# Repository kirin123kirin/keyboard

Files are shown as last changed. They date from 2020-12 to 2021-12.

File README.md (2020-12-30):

# 自作キーボードの沼

## 以下の要件を満たす分割キーボードがないから作りたい。

* 癖のない一般的なキーピッチ、配列である
* 日本語配列である
* 光らなくてよい
* 一般的なテンキーレスを普通に左右に分割しただけで特殊な配列ではないこと
* 「6」、「Y」、「B」は右手で押す
* IME切り替えはトグルではなくMacのように「英数」、「かな」で独立したキー切替をする
* USB Type-C
* 左右どちら側のUSBに接続しても使える
* キーキャップにかな表記はいらない
* キーキャップに英語配列時の記号も小さく表記したい
* Thinkpad トラックポイントを右手側につけたい

## 沼１：レイアウト
1. [レイアウトを考える](http://www.keyboard-layout-editor.com/)

## 沼２：回路基盤設計
2. [回路図の書き方](https://www.youtube.com/watch?v=dNfaLM5PUVM&list=PLKe0_8RR2yrSu2fZAs2D8_bfYQ3JGBO-w)
3. [自動レイアウト](https://github.com/yskoht/keyboard-layouter)
4. [自動配線](https://freerouting.mihosoft.eu/)
5. [Elecrow発注データ作成は自作](https://github.com/kirin123kirin/keyboard/blob/main/pcb/basic_L/garbar.py)

## 沼３：ファームウェア書き込み
6. [半自動firmware作成](https://kbfirmware.com/)
   -> Or import from keyboard-layout-editor.comの下のテキストボックスにKyeboard Layout Editorのraw dataの内容をコピペ

## 沼４：スイッチ選び
7. 赤軸(軽い) or 黒軸(重い) / CherryMX(90円) or KailhBox(40円)

## 沼５：キーキャップ選び
8. [Filco交換用](https://amzn.to/37BaPCG)

9. [刻印サービス](https://yushakobo.jp/keycap-laser-marking/)
  -> 高いのでやめる

## 沼６：ケース作成
10. [Plate & Case Builder](http://builder.swillkb.com/)
  -> keyboard-layout-editorのRAWデータからCADデータ自動作成

11. [Kicad PCB to Fusion360](https://garchiving.com/output-3d-model-with-kicad/)

12. [Elecrow 3D Printing Service](https://www.elecrow.com/3d-printing-service.html)

## 沼７：トラックポイントをつける
TODO

## かかった費用

| カテゴリー 	| 購入製品 	| 個数  	| 単価 	| 小計(円)  	| 購入店 	|
| :--- | :---  | ---:  | ---: | ---: | :---  |
| マイコンボード 	| [Elite-C](https://yushakobo.jp/shop/elite-c/) 	| 2 	| 2805 	| 5610 	| [遊舎工房](https://yushakobo.jp/shop/elite-c/) 	|
| マイコンボードソケット化 	| [ピンヘッダー ストリップ ピンソケット 40ピン](https://amzn.to/2Ml5kjq) 	| 1 	| 720 	| 720 	| [Amazon](https://amzn.to/2Ml5kjq) 	|
| PCB基盤 	| 左 	| 104.1 	| $27.35  	| 2,847 	| ElecrowPCB 	|
| PCB基盤 	| 右 	| 104.1 	| $36.37  	| 3,786 	| ElecrowPCB 	|
| PCB基盤 	| 送料 	| 104.1 	| $20.12  	| 2,094 	| ElecrowPCB 	|
| ケース 	| 左右光造形 	| 104.1 	| $70 	| 7,287 	| Elecrow3DPrintService 	|
| ケース 	| トッププレート 	| 104.1 	| $20 	| 2,082 	| Elecrow3DPrintService 	|
| ケース 	| 送料 	| 104.1 	| $14 	| 1,447  	| Elecrow3DPrintService 	|
| キースイッチ 	| [Kailh Box黒軸](https://amzn.to/3h1IFUD) 	| 104.1 	| $34 	| 3508.17  	| Aliexpress 	|
| スタビライザー 	| [ブラックチェリースタビライザー](https://ja.aliexpress.com/item/32831318362.html?spm=a2g0s.9042311.0.0.46c54c4d9BF958) 	| 104.1 	| $5.90 	| 614.19 	| Aliexpress 	|
| キーキャップ 	| [Majestouch 交換用キーキャップセット 日本語108キー・かななし](https://amzn.to/37BaPCG) 	| 1 	| 3420 	| 3420 	| [Amazon](https://amzn.to/37BaPCG)	|
| 配線類 	| [ダイオード500個](https://amzn.to/2Wz1wNc) 	| 1 	| 1082 	| 1082 	| [Amazon](https://amzn.to/2Wz1wNc) 	|
| 配線類 	| [抵抗セット](https://amzn.to/3nESg6m) 	| 1 	| 890 	| 890 	| [Amazon](https://amzn.to/3nESg6m) 	|
| 配線類 	| [はんだ線](https://amzn.to/3mBjyJs)、[フラックス](https://amzn.to/3p1iNLk) 	| 1 	| 916 	| 916 	| [Amazon](https://amzn.to/3p1iNLk) 	|
| TRRS 	| [３．５ｍｍ４極ミニジャック　基板取付用　ＭＪ－４ＰＰ－９](https://akizukidenshi.com/catalog/g/gC-06070/) 	| 2 	| 55 	| 110 	| 秋月通商 	|
| デバック用 	| [ブレッドボード5個セット](https://amzn.to/3nD7uZn) 	| 1 	| 750 	| 750 	| [Amazon](https://amzn.to/3nD7uZn) 	|
| デバック用 	| [マスキングテープ3個](https://amzn.to/2J5NEa9) 	| 1 	| 498 	| 498 	| [Amazon](https://amzn.to/2J5NEa9) 	|
| デバック用 	| ジャンパー線、[タクトスイッチ10個](https://amzn.to/3mDJrrU) 	| 1 	| 660 	| 660 	| 秋月通商,[Amazon](https://amzn.to/3mDJrrU) 	|
| 工具 	| [はんだキット](https://amzn.to/2WwUdWA) 	| 1 	| 3599 	| 3599 	| [Amazon](https://amzn.to/2WwUdWA) 	|
| 工具 	| [ノギス](https://amzn.to/3mIHx9L) 	| 1 	| 799 	| 799 	| [Amazon](https://amzn.to/3mIHx9L)	|
| レイアウト設計 	| [キーボードレイアウト設計](http://www.keyboard-layout-editor.com/) 	| 1 	| 0 	| 0 	| OSS 	|
| PCB設計 	| [Kicad](https://kicad.org/) 	| 1 	| 0 	| 0 	| OSS 	|
| PCB設計 	| [基盤自動レイアウトプラグイン](https://github.com/yskoht/keyboard-layouter) 	| 1 	| 0 	| 0 	| OSS 	|
| PCB設計 	| [freerouting(基盤自動配線)](https://github.com/freerouting/freerouting) 	| 1 	| 0 	| 0 	| OSS 	|
| ケース、トッププレート設計 	| [Fusion360個人利用](https://www.autodesk.co.jp/products/fusion-360/overview) 	| 1 	| 0 	| 0 	| Adobe 	|
| Firmware 	| [qmk_firmware](https://github.com/qmk/qmk_firmware) 	| 1 	| 0 	| 0 	| Github 	|
| Firmware 	| [Keyboard Firmware Builder](https://kbfirmware.com/) 	| 1 	| 0 	| 0 	| OSS 	|
| Firmwareビルド用 	| [Ubuntu18.04LTS Server](http://ftp.riken.jp/Linux/ubuntu-releases/18.04/) 	| 1 	| 0 	| 0 	| Ubuntu 	|
| Firmwareソース編集用	| [Visual Studio2019Comunity](https://visualstudio.microsoft.com/ja/downloads/) 	| 1 	| 0 	| 0 	| MicroSoft 	|
| 	| 	| 	| 合計 	| 42,334円	|

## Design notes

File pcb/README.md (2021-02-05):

** qmk data version rev1 later **

# 自作基盤設計データ
## Lisense
This software is released under the [Creative Commons CC-BY-SA 4.0 License](https://creativecommons.org/licenses/by-sa/4.0/legalcode), see LICENSE.

## [Powerd by Kicad](https://kicad.org/)

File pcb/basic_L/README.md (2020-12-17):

Powered by [Keyboard Layouter](https://github.com/yskoht/keyboard-layouter) plugin.

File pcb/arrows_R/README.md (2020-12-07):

# Keyboard Layouter Playground

A sample circuit and netlist to quickly try the [Keyboard Layouter](https://github.com/yskoht/keyboard-layouter) plugin.

The sample JSON files are follow:

- ANSI 104
- ISO 105
- ErgoDox
- Atreus

## Curcuit

curcuit

## Footprint

footprint

## Lisense

This software is released under the [Creative Commons CC-BY-SA 4.0 License](https://creativecommons.org/licenses/by-sa/4.0/legalcode), see LICENSE.

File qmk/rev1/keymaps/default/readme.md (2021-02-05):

# Left Elite-C PIN asign

```
      Wheel Mouse KEY   PIN_L                               PIN_R KEY   Mouse Wheel 
                                                            Vbus                    
                        D3    TX                      RAW   B0                      
                  SIG   D2    RX                            GND                     
                        GND                                 RST                     
                        GND                                 VCC                     
                  SDA   D1    2     SDA         A3    21    F4                      
                  SCL   D0    3     SCL         A2    20    F5    COL5              
                  ROW6  D4    4                 A1    19    F6    COL4              
                  ROW5  C6    5                 A0    18    F7    COL3              
                  ROW4  D7    6                 SCLK  15    B1                      
                  ROW3  E6    7                 MISO  14    B3    COL2              
                  ROW2  B4    8                 MOSI  16    B2    COL1              
                  COL0  B5    9                 A10   10    B6    ROW1              
PIN_B                         B7    D5    C7    F1    F0                            
KEY                                                                                 
Mouse                                                                               
Wheel                                                                               
```

# Right Elite-C PIN asign

```
      Wheel Mouse KEY   PIN_L                               PIN_R KEY   Mouse Wheel 
                                                            Vbus                    
                        D3    TX                      RAW   B0                      
                  SIG   D2    RX                            GND                     
                  SIG   GND                                 RST                     
                        GND                                 VCC                     
                  SDA   D1    2     SDA         A3    21    F4                      
                  SCL   D0    3     SCL         A2    20    F5    ROW12             
                  COL6  D4    4                 A1    19    F6    ROW11             
                  COL7  C6    5                 A0    18    F7    ROW10             
                  COL8  D7    6                 SCLK  15    B1    ROW9              
                  COL9  E6    7                 MISO  14    B3    ROW8              
                  COL10 B4    8                 MOSI  16    B2    ROW7              
                  COL11 B5    9                 A10   10    B6    COL17             
PIN_B                         B7    D5    C7    F1    F0                            
KEY                           COL12 COL13 COL14 COL15 COL16                         
Mouse                                                                               
Wheel                                                                               
```

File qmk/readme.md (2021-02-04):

# gammy keyboards

日本語レイアウトの分割キーボード用

Keyboard Maintainer: [kirin123kirin](https://github.com/kirin123kirin)  
Hardware Supported: Elite-C(atmega32u4) Pro Micro互換

[QMK firmware](https://github.com/qmk/qmk_firmware)環境を作った後にビルドする

## qmk_firmware 書き込み準備
```bash
cd /tmp
git clone --recurse-submodules https://github.com/qmk/qmk_firmware.git
git clone https://github.com/kirin123kirin/keyboard.git tmp_

mv ./tmp_/qmk ./qmk_firmware/keyboards/gammy
rm -rf ./tmp_
cd ./qmk_firmware

## buildのみ場合
make gammy/rev0:default

## そのままfirmware書き込む場合
make gammy/rev0:default:dfu
ls -l *.hex

```

## 参考
* [QMKセットアップ](https://docs.qmk.fm/#/getting_started_build_tools)
* [QMK makeガイド](https://docs.qmk.fm/#/getting_started_make_guide)
* [QMK Newbs Guide](https://docs.qmk.fm/#/newbs)

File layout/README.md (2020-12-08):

# キーボードレイアウトは以下で作成した

[keyboard-layout-editor.com](http://www.keyboard-layout-editor.com/)

## basic split layout
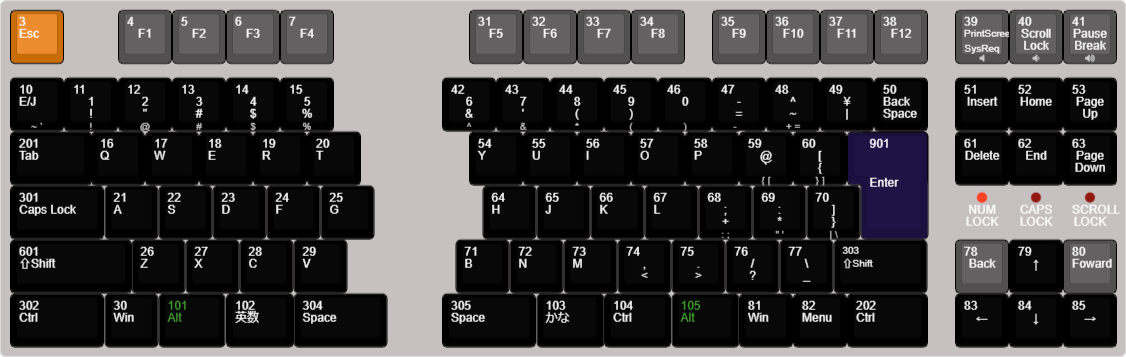
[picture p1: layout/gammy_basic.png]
gammy


# TODO
ergo split layout
extention split layout

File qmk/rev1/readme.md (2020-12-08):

# gammy keyboards

日本語レイアウトの分割キーボード用

Keyboard Maintainer: [kirin123kirin](https://github.com/kirin123kirin)  
Hardware Supported: Elite-C(atmega32u4) Pro Micro互換

[QMK firmware](https://github.com/qmk/qmk_firmware)環境を作った後にビルドする

## buildのみ場合

```bash
make gammy/rev1:default
```

## そのままfirmware書き込む場合

```bash
make gammy/rev1:default:dfu
```

## 参考
* [QMKセットアップ](https://docs.qmk.fm/#/getting_started_build_tools)
* [QMK makeガイド](https://docs.qmk.fm/#/getting_started_make_guide)
* [QMK Newbs Guide](https://docs.qmk.fm/#/newbs)

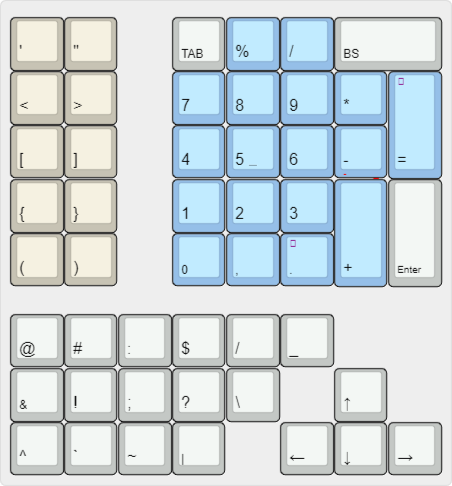
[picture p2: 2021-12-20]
pcb/kigokey/kigokey.png

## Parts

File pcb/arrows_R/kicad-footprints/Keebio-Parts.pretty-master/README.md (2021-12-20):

# Keebio-Parts.pretty
Various KiCAD footprints for mechanical keyboard parts. Accuracy of the footprints are not guaranteed, but a best effort has been made.

For the component symbols of some of these parts, see https://github.com/keebio/keebio-components.

## Miscellaneous Notes

### Zig-zag header holes for Pro Micro/Elite-C
The staggered header holes only work okay for connecting a controller to the PCB, so soldering is still recommended when using these footprints. But the benefit of using them is that the pins will be held straight on their own while trying to solder them on, so they are preferred over the normal footprint in that respect.

### Choc stab cutout outlines
The stab PCB/plate cutouts for Choc switches are still experimental, so use them at your own risk. The cutouts are based on measurements done on an MSI Vigor GK50 keyboard, with adjustments to handle available Kailh Choc keycaps. The stab offset difference between the GK50 keycaps and Kailh ones is 1mm.

License
-------
These files are released under the MIT License.

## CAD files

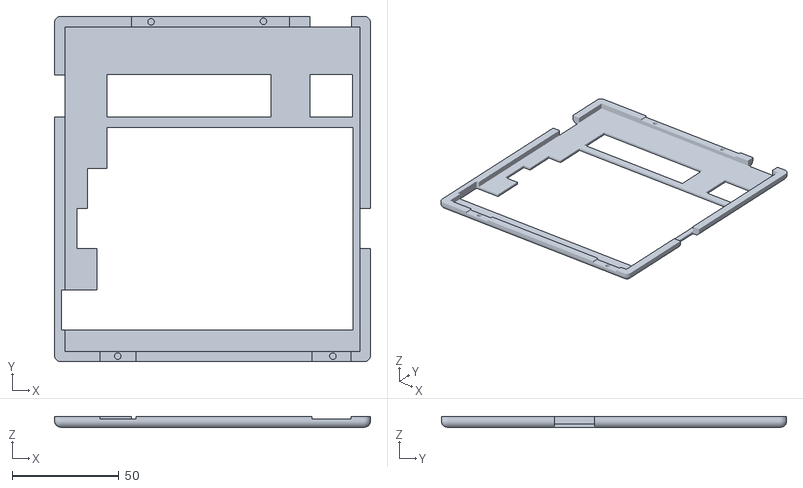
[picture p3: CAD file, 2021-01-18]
case/basic_L/case_L_top.stl
148.2 x 162.0 x 5.00

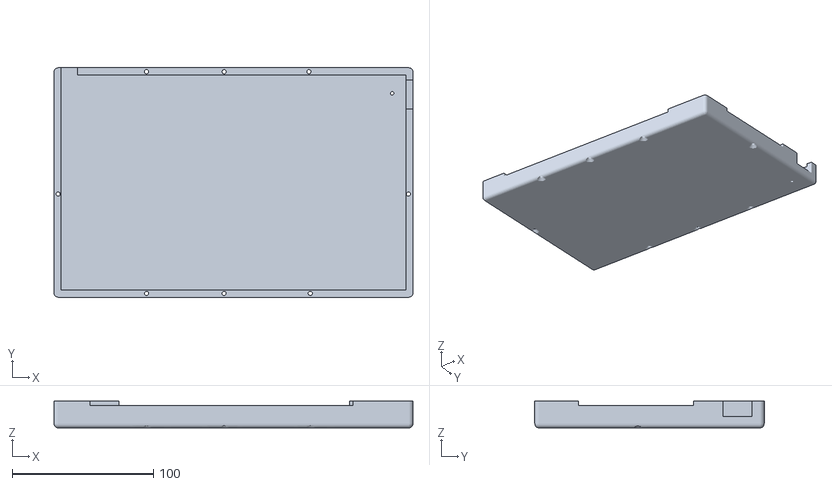
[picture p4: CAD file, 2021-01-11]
case/basic_R/case_R_bottom.stl
254.3 x 162.6 x 19.0

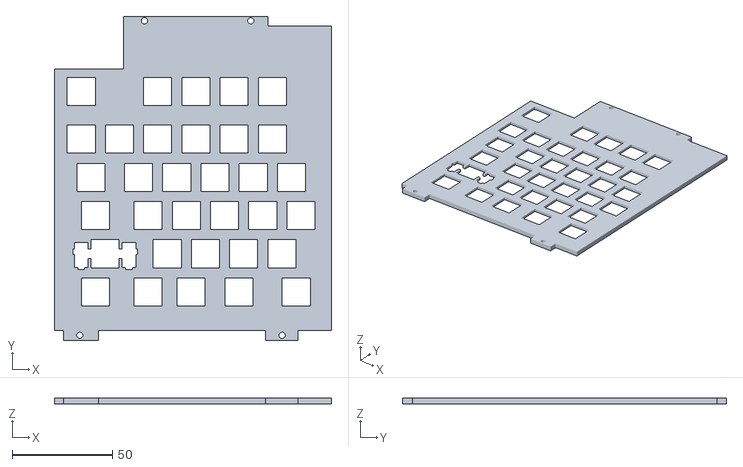
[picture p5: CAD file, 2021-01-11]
case/basic_L/plate_L.stl
138.2 x 161.5 x 3.00

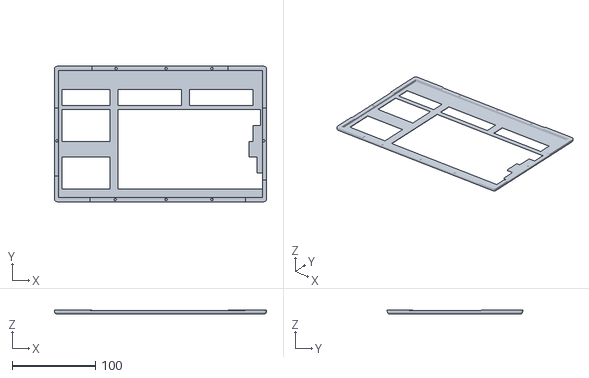
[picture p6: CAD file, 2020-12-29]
case/basic_R/case_R_top.stl
254.3 x 162.6 x 5.00

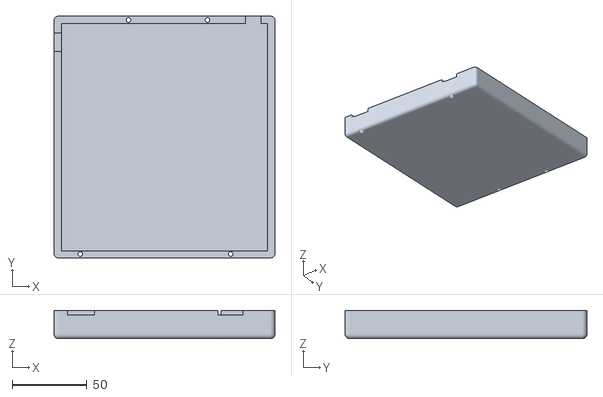
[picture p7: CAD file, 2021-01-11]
case/basic_L/case_L_bottom.stl
148.2 x 162.2 x 19.0

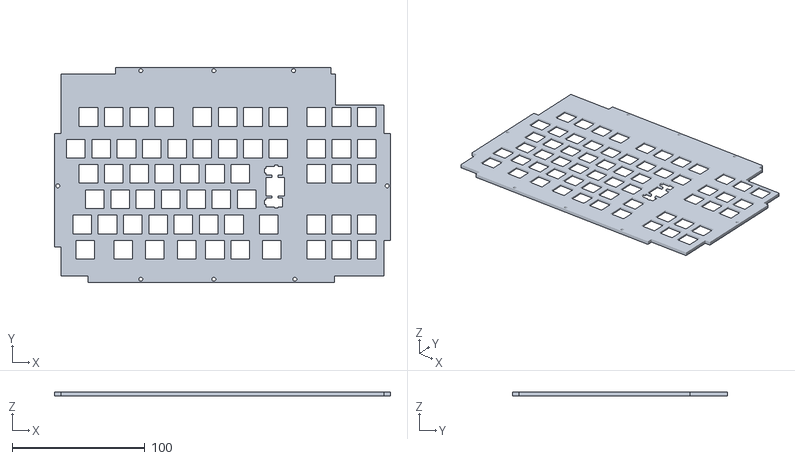
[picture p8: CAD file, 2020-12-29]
case/basic_R/plate_R.stl
253.0 x 161.8 x 3.00

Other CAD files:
case/basic_L/plate_L.dxf
case/basic_R/plate_R.dxf

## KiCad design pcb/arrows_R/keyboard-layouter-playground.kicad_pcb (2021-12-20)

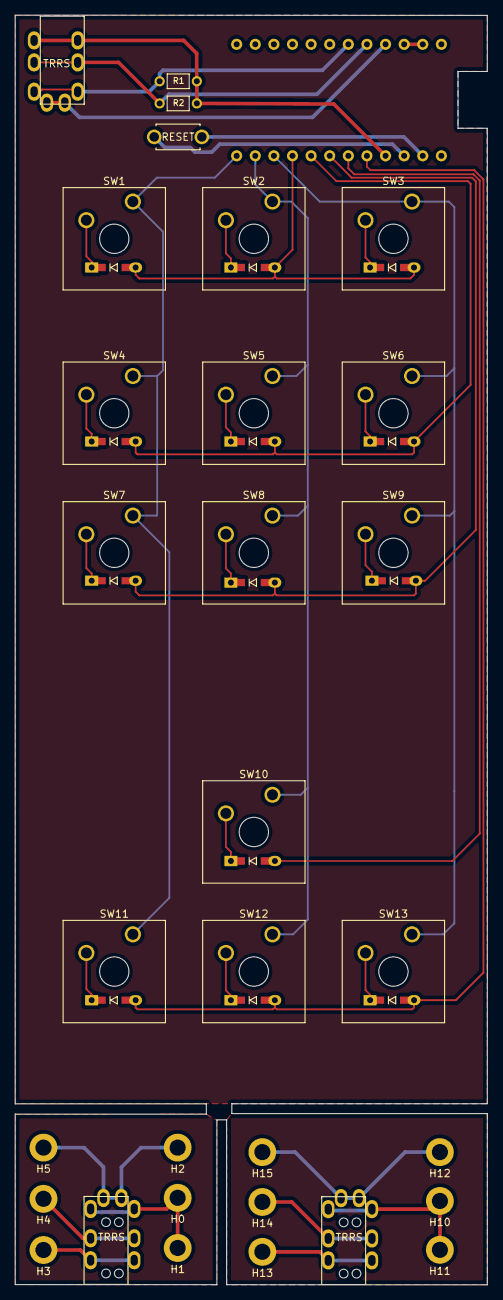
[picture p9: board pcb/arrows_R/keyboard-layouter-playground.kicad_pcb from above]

Board: 2 copper layers, 64.4 x 173.3 mm, 45 parts (1 on the bottom side), 36 nets.

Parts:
D1, D2, D3, D4, D5, D6, D7, D8, D9, D10, D11, D12, D13: DIODE; D3_TH
H0, H10: MIC-Left; MountingHole_2.2mm_M2_ISO14580_Pad
H1, H11: MIC-Right; MountingHole_2.2mm_M2_ISO14580_Pad
H2, H5, H12, H15: GND; MountingHole_2.2mm_M2_ISO14580_Pad
H3, H13: Left; MountingHole_2.2mm_M2_ISO14580_Pad
H4, H14: Right; MountingHole_2.2mm_M2_ISO14580_Pad
J1, J2, J3: MJ-4PP-9
R1, R2: 4.7k; R
SW1, SW2, SW3, SW4, SW5, SW6, SW7, SW8, SW9, SW10, SW11, SW12, SW13: SW_Push; SW_Cherry_MX_1.00u_Plate
SW_RST2: SW_PUSH; ResetSW
U1: ProMicro; ProMicro_v3.5

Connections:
COL1: SW1.1, SW4.1, SW7.1, SW11.1, U1.13
COL2: SW2.1, SW5.1, SW8.1, SW10.1, SW12.1, U1.14
COL3: SW3.1, SW6.1, SW9.1, SW13.1, U1.15
unnamed: D1.1, SW1.2
unnamed: D2.1, SW2.2
unnamed: D3.1, SW3.2
unnamed: D4.1, SW4.2
unnamed: D5.1, SW5.2
unnamed: D6.1, SW6.2
unnamed: D7.1, SW7.2
unnamed: D8.1, SW8.2
unnamed: D9.1, SW9.2
unnamed: D10.1, SW10.2
unnamed: D11.1, SW11.2
unnamed: D12.1, SW12.2
unnamed: D13.1, SW13.2
unnamed: H0.1, H1.1, J1.D
unnamed: H2.1, H5.1, J1.A
unnamed: H3.1, J1.B
unnamed: H4.1, J1.C
unnamed: H10.1, H11.1, J3.D
unnamed: H12.1, H15.1, J3.A
unnamed: H13.1, J3.B
unnamed: H14.1, J3.C
unnamed: J2.A, U1.4
unnamed: J2.B, R1.2, R2.2, U1.21
unnamed: J2.D, R1.1, U1.6
unnamed: SW_RST2.1, U1.22
unnamed: SW_RST2.2, U1.23
unnamed: U1.2, U1.3
SDA2: J2.C, R2.1, U1.5
row1: D1.2, D2.2, D3.2, U1.16
row2: D4.2, D5.2, D6.2, U1.17
row3: D7.2, D8.2, D9.2, U1.18
row4: D10.2, U1.19
row5: D11.2, D12.2, D13.2, U1.20

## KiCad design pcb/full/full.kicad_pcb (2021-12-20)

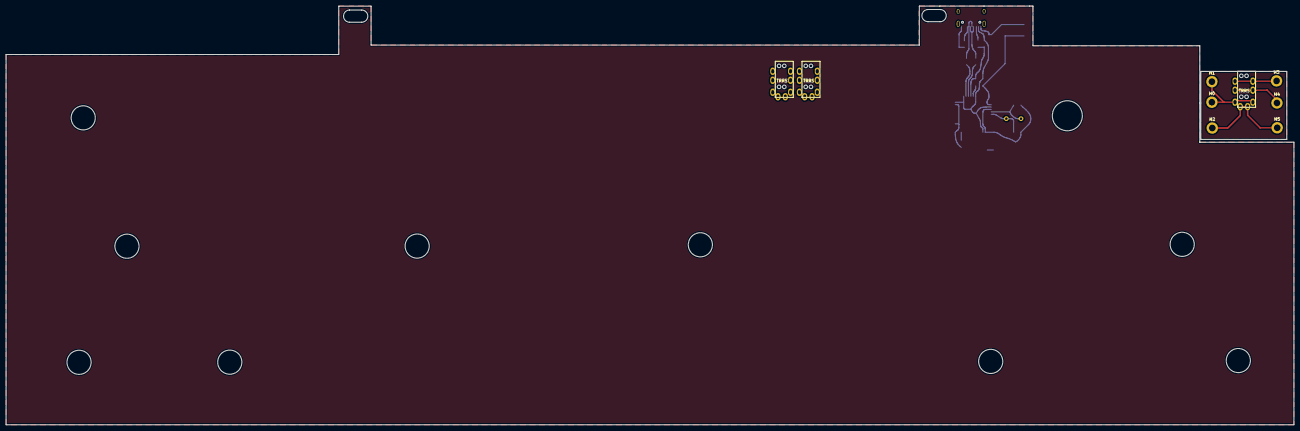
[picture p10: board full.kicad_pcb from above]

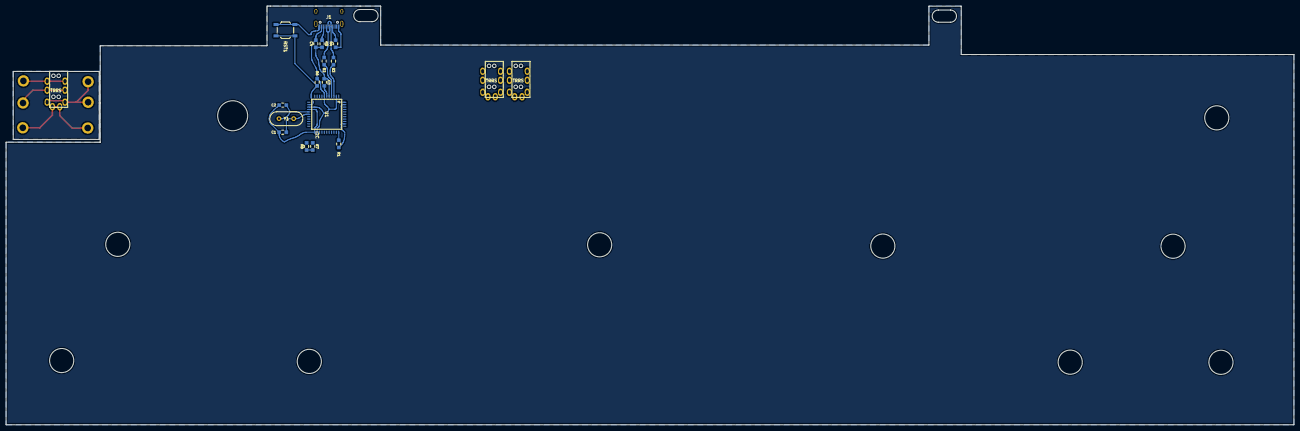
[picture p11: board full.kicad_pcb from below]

Board: 2 copper layers, 429.5 x 139.6 mm, 25 parts (15 on the bottom side), 15 nets.

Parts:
C1, C2: 22p; 2012M
C3, C4: 1u; 2012M
H0: MIC-Left; MountingHole_2.2mm_M2_ISO14580_Pad
H1: MIC-Right; MountingHole_2.2mm_M2_ISO14580_Pad
H2, H5: GND; MountingHole_2.2mm_M2_ISO14580_Pad
H3: Left; MountingHole_2.2mm_M2_ISO14580_Pad
H4: Right; MountingHole_2.2mm_M2_ISO14580_Pad
J1: MJ-4PP-9
J1#2: TYPE-C-31-M-12
J2, J3: AudioJack4; MJ-4PP-9
R1, R6: 10k; 2012M
R2, R3: 22; 2012M
R4, R5, R7, R8: 5.1k; 2012M
RST1: SW_Push; SW_SPST_TL3342
U1: ATmega32U4-AU; TQFP44
Y1: 16MHz; Crystal-HC-49-S

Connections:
D+: R2.1, U1.4
D-: R3.1, U1.3
GND: C1.2, C2.2, C3.2, C4.2, J1#2.A1B12, J1#2.B1A12, R1.1, R4.1, R5.1, RST1.1, U1.5, U1.15, U1.23, U1.35, U1.43
unnamed: C1.1, U1.17, Y1.1
unnamed: C2.1, U1.16, Y1.2
unnamed: C3.1, U1.6
unnamed: J1#2.A5, R4.2
unnamed: J1#2.A6, J1#2.B6, R2.2
unnamed: J1#2.A7, J1#2.B7, R3.2
unnamed: J1#2.B5, R5.2
unnamed: R1.2, U1.33
RESET: R6.1, RST1.2, U1.13
SCL: R7.1, U1.18
SDA: R8.1, U1.19
VCC: C4.1, J1#2.A4B9, J1#2.B4A9, R6.2, R7.2, R8.2, U1.2, U1.7, U1.14, U1.24, U1.34, U1.44

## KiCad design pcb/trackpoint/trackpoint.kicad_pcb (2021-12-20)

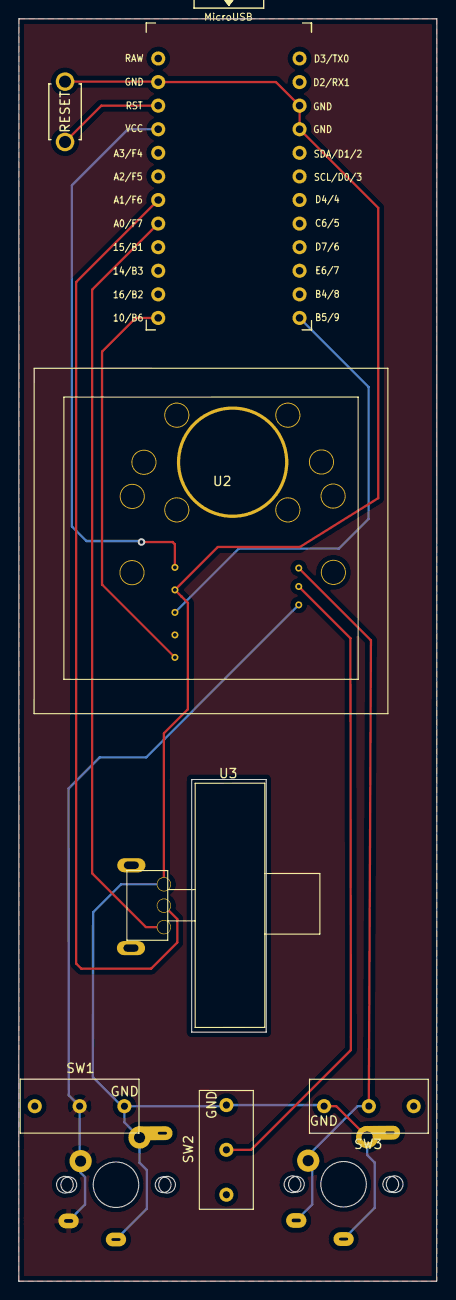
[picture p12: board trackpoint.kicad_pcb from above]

Board: 2 copper layers, 45.0 x 135.9 mm, 9 parts (0 on the bottom side), 10 nets.

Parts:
SW0: SW_RESET; ResetSW
SW01, SW03: SW_Push; CherryMX_ChocV2_1u
SW1, SW2, SW3: MouseClick; mouse_click
U1: ProMicro; ProMicro_v3.5
U2: trackpoint_R61
U3: mouse_wheel

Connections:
CLK: U1.12, U2.6
DATA: U1.13, U2.1
GND: SW0.2, SW01.2, SW1.2, SW2.2, SW03.2, SW3.2, U1.3, U1.4, U1.23, U2.7, U3.1
unnamed: SW0.1, U1.22
unnamed: SW01.1, SW1.1, U2.3
unnamed: SW2.1, U2.4
unnamed: SW03.1, SW3.1, U2.5
unnamed: U1.17, U3.3
unnamed: U1.18, U3.2
VCC: U1.21, U2.8

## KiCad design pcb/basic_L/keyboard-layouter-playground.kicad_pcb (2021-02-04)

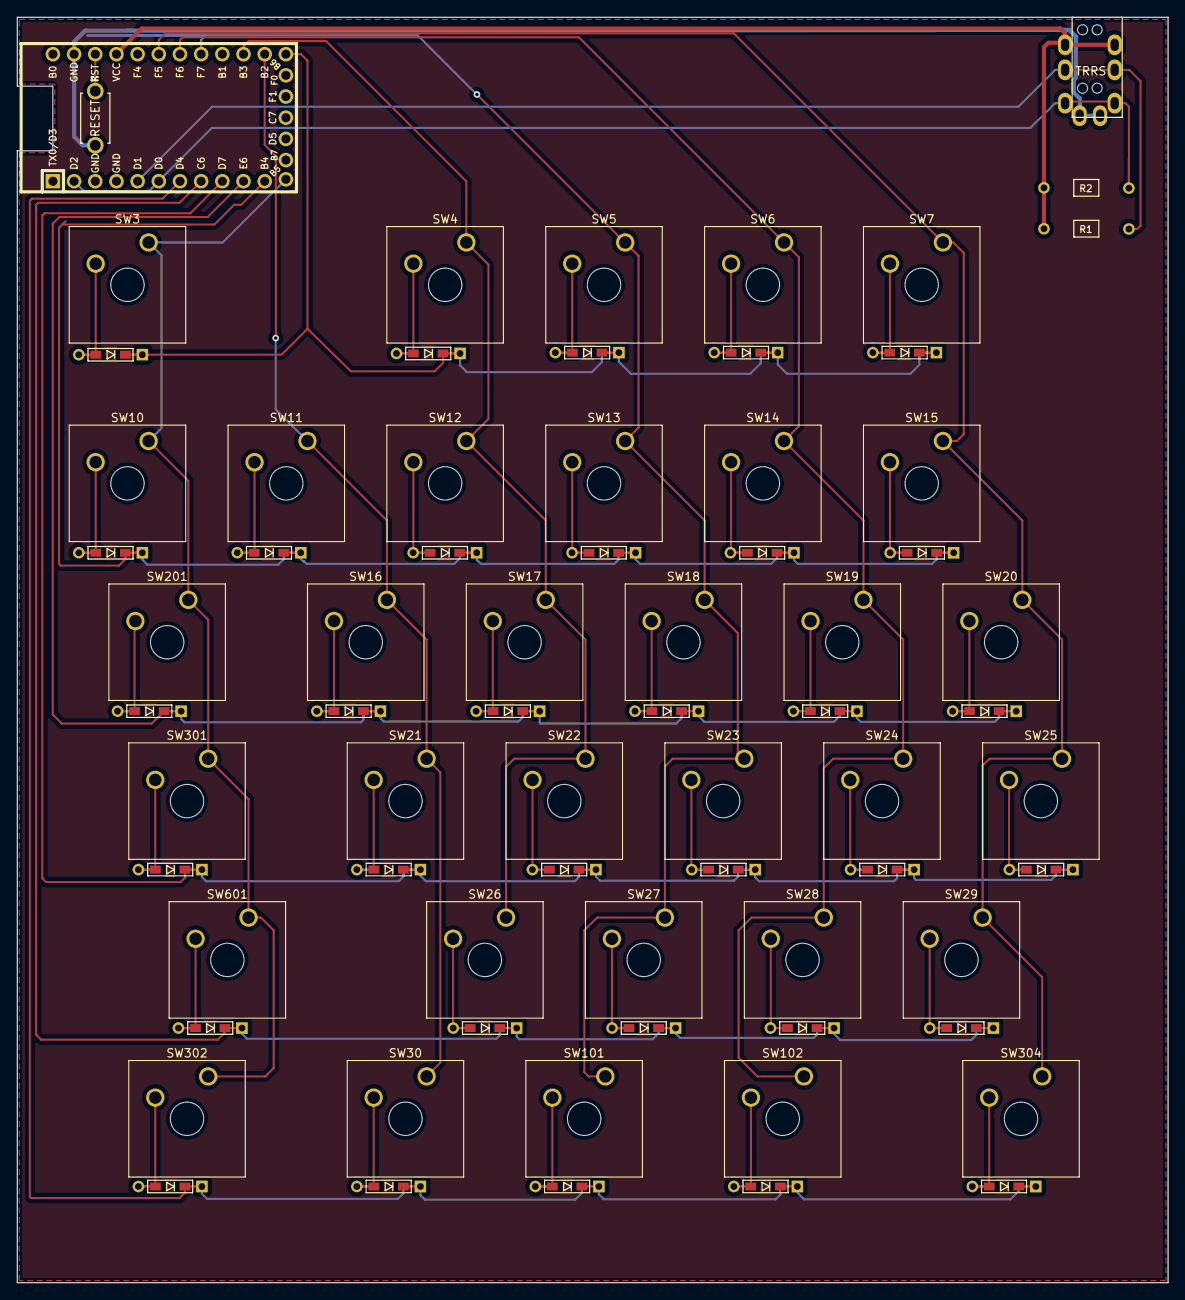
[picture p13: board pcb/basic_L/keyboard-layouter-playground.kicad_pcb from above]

Board: 2 copper layers, 138.0 x 151.8 mm, 71 parts (0 on the bottom side), 50 nets.

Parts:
D3, D4, D5, D6, D7, D10, D11, D12, D13, D14, D15, D16, D17, D18, D19, D20, D21, D22, D23, D24, D25, D26, D27, D28, D29, D30, D101, D102, D201, D301, D302, D304, D601: DIODE; D3_TH_SMD_Horizontal
J1: MJ-4PP-9
R1, R2: 4.7k; R
SW3, SW4, SW5, SW6, SW7, SW10, SW11, SW12, SW13, SW14, SW15, SW16, SW17, SW18, SW19, SW20, SW21, SW22, SW23, SW24, SW25, SW26, SW27, SW28, SW29, SW30: SW_Push; SW_Cherry_MX_1.00u_Plate
SW101, SW102: SW_Push; SW_Cherry_MX_1.25u_Plate
SW201: SW_Push; SW_Cherry_MX_1.50u_Plate
SW301, SW302, SW304: SW_Push; SW_Cherry_MX_1.75u_Plate
SW601: SW_Push; SW_Cherry_MX_2.25u_Plate
SW_RST1: SW_PUSH; ResetSW
U1: Elite-C-keebio; Elite-C

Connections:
COL0: SW3.1, SW10.1, SW201.1, SW301.1, SW302.1, SW601.1, U1.12
COL1: SW11.1, SW16.1, SW21.1, SW30.1, U1.14
COL2: SW4.1, SW12.1, SW17.1, SW22.1, SW26.1, U1.15
COL3: SW5.1, SW13.1, SW18.1, SW23.1, SW27.1, SW101.1, U1.17
COL4: SW6.1, SW14.1, SW19.1, SW24.1, SW28.1, SW102.1, U1.18
COL5: SW7.1, SW15.1, SW20.1, SW25.1, SW29.1, SW304.1, U1.19
GND: J1.A, SW_RST1.2, U1.23
unnamed: D3.1, SW3.2
unnamed: D4.1, SW4.2
unnamed: D5.1, SW5.2
unnamed: D6.1, SW6.2
unnamed: D7.1, SW7.2
unnamed: D10.1, SW10.2
unnamed: D11.1, SW11.2
unnamed: D12.1, SW12.2
unnamed: D13.1, SW13.2
unnamed: D14.1, SW14.2
unnamed: D15.1, SW15.2
unnamed: D16.1, SW16.2
unnamed: D17.1, SW17.2
unnamed: D18.1, SW18.2
unnamed: D19.1, SW19.2
unnamed: D20.1, SW20.2
unnamed: D21.1, SW21.2
unnamed: D22.1, SW22.2
unnamed: D23.1, SW23.2
unnamed: D24.1, SW24.2
unnamed: D25.1, SW25.2
unnamed: D26.1, SW26.2
unnamed: D27.1, SW27.2
unnamed: D28.1, SW28.2
unnamed: D29.1, SW29.2
unnamed: D30.1, SW30.2
unnamed: D101.1, SW101.2
unnamed: D102.1, SW102.2
unnamed: D201.1, SW201.2
unnamed: D301.1, SW301.2
unnamed: D302.1, SW302.2
unnamed: D304.1, SW304.2
unnamed: D601.1, SW601.2
unnamed: J1.D, R2.1, U1.2, U1.6
unnamed: SW_RST1.1, U1.22
SDA1: J1.C, R1.1, U1.5
VCC: J1.B, R1.2, R2.2, U1.21
row1: D3.2, D4.2, D5.2, D6.2, D7.2, U1.13
row2: D10.2, D11.2, D12.2, D13.2, D14.2, D15.2, U1.11
row3: D16.2, D17.2, D18.2, D19.2, D20.2, D201.2, U1.10
row4: D21.2, D22.2, D23.2, D24.2, D25.2, D301.2, U1.9
row5: D26.2, D27.2, D28.2, D29.2, D601.2, U1.8
row6: D30.2, D101.2, D102.2, D302.2, D304.2, U1.7

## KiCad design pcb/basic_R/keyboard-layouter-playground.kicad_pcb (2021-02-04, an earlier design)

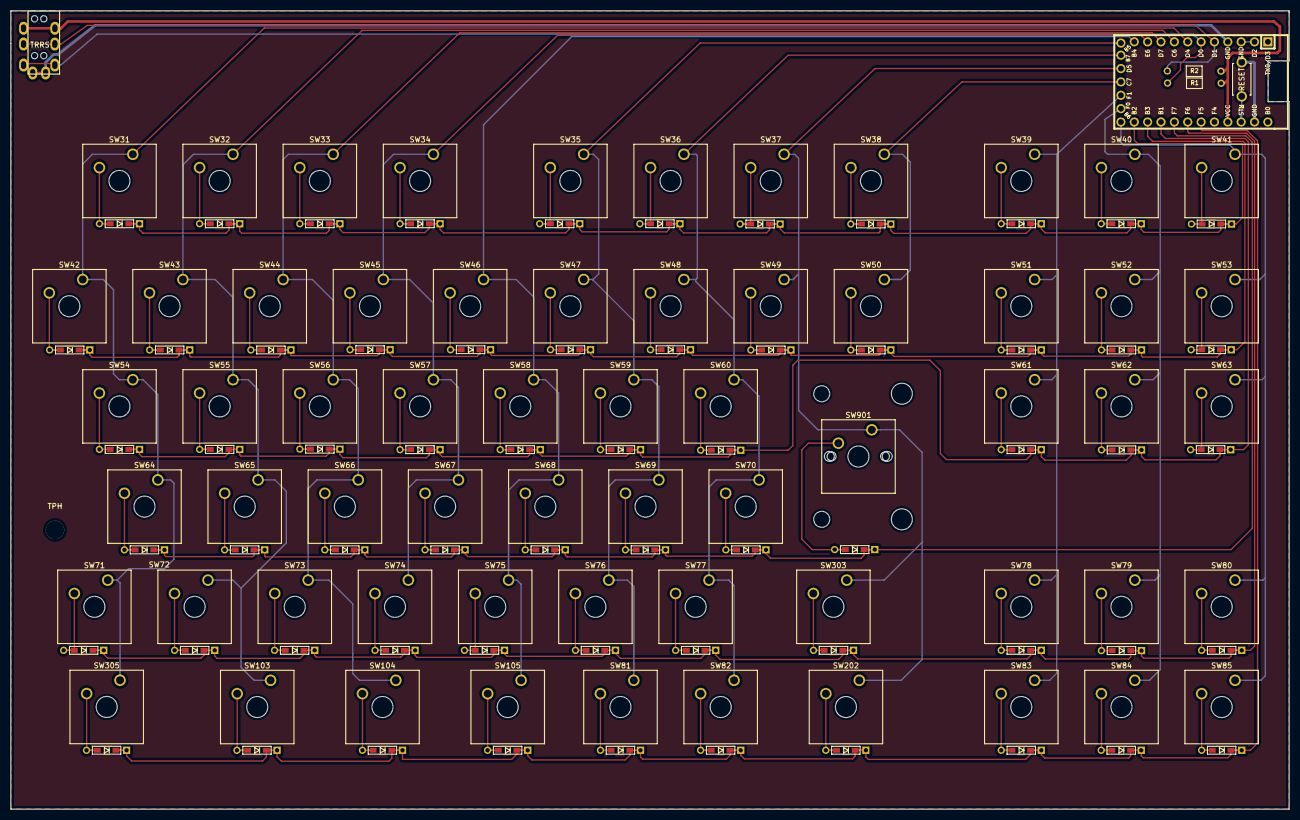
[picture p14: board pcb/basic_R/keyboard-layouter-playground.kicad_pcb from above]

Board: 2 copper layers, 243.0 x 151.8 mm, 130 parts (0 on the bottom side), 87 nets.

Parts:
D31, D32, D33, D34, D35, D36, D37, D38, D39, D40, D41, D42, D43, D44, D45, D46, D47, D48, D49, D50, D51, D52, D53, D54, D55, D56, D57, D58, D59, D60, D61, D62, D63, D64, D65, D66, D67, D68, D69, D70, D71, D72, D73, D74, D75, D76, D77, D78, D79, D80, D81, D82, D83, D84, D85, D103, D104, D105, D202, D303, D305, D901: DIODE; D3_TH_SMD_Horizontal
J2: MJ-4PP-9
R1, R2: 4.7k; R
SW31, SW32, SW33, SW34, SW35, SW36, SW37, SW38, SW39, SW40, SW41, SW42, SW43, SW44, SW45, SW46, SW47, SW48, SW49, SW50, SW51, SW52, SW53, SW54, SW55, SW56, SW57, SW58, SW59, SW60, SW61, SW62, SW63, SW64, SW65, SW66, SW67, SW68, SW69, SW70, SW71, SW72, SW73, SW74, SW75, SW76, SW77, SW78, SW79, SW80, SW81, SW82, SW83, SW84, SW85: SW_Push; SW_Cherry_MX_1.00u_Plate
SW103, SW104, SW105: SW_Push; SW_Cherry_MX_1.25u_Plate
SW202: SW_Push; SW_Cherry_MX_1.50u_Plate
SW303, SW305: SW_Push; SW_Cherry_MX_1.75u_Plate
SW901: SW_Push; SW_Cherry_MX_ISOEnter_Stabilizer_5pin
SW_RST2: SW_PUSH; ResetSW
TPH: MountingHole_3.5mm
U2: Elite-C

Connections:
COL9: SW31.1, SW42.1, SW54.1, SW64.1, SW71.1, SW305.1, U2.7
COL10: SW32.1, SW43.1, SW55.1, SW65.1, SW72.1, SW103.1, U2.8
COL11: SW33.1, SW44.1, SW56.1, SW66.1, SW73.1, SW104.1, U2.9
COL12: SW34.1, SW45.1, SW57.1, SW67.1, SW74.1, U2.10
COL13: SW46.1, SW58.1, SW68.1, SW75.1, SW105.1, U2.11
COL14: SW35.1, SW47.1, SW59.1, SW69.1, SW76.1, SW81.1, U2.12
COL15: SW36.1, SW48.1, SW60.1, SW70.1, SW77.1, SW82.1, U2.25
COL16: SW37.1, SW49.1, SW202.1, SW303.1, SW901.1, U2.26
COL17: SW38.1, SW50.1, U2.27
COL18: SW39.1, SW51.1, SW61.1, SW78.1, SW83.1, U2.28
COL19: SW40.1, SW52.1, SW62.1, SW79.1, SW84.1, U2.29
COL20: SW41.1, SW53.1, SW63.1, SW80.1, SW85.1, U2.13
unnamed: D31.1, SW31.2
unnamed: D32.1, SW32.2
unnamed: D33.1, SW33.2
unnamed: D34.1, SW34.2
unnamed: D35.1, SW35.2
unnamed: D36.1, SW36.2
unnamed: D37.1, SW37.2
unnamed: D38.1, SW38.2
unnamed: D39.1, SW39.2
unnamed: D40.1, SW40.2
unnamed: D41.1, SW41.2
unnamed: D42.1, SW42.2
unnamed: D43.1, SW43.2
unnamed: D44.1, SW44.2
unnamed: D45.1, SW45.2
unnamed: D46.1, SW46.2
unnamed: D47.1, SW47.2
unnamed: D48.1, SW48.2
unnamed: D49.1, SW49.2
unnamed: D50.1, SW50.2
unnamed: D51.1, SW51.2
unnamed: D52.1, SW52.2
unnamed: D53.1, SW53.2
unnamed: D54.1, SW54.2
unnamed: D55.1, SW55.2
unnamed: D56.1, SW56.2
unnamed: D57.1, SW57.2
unnamed: D58.1, SW58.2
unnamed: D59.1, SW59.2
unnamed: D60.1, SW60.2
unnamed: D61.1, SW61.2
unnamed: D62.1, SW62.2
unnamed: D63.1, SW63.2
unnamed: D64.1, SW64.2
unnamed: D65.1, SW65.2
unnamed: D66.1, SW66.2
unnamed: D67.1, SW67.2
unnamed: D68.1, SW68.2
unnamed: D69.1, SW69.2
unnamed: D70.1, SW70.2
unnamed: D71.1, SW71.2
unnamed: D72.1, SW72.2
unnamed: D73.1, SW73.2
unnamed: D74.1, SW74.2
unnamed: D75.1, SW75.2
unnamed: D76.1, SW76.2
unnamed: D77.1, SW77.2
unnamed: D78.1, SW78.2
unnamed: D79.1, SW79.2
unnamed: D80.1, SW80.2
unnamed: D81.1, SW81.2
unnamed: D82.1, SW82.2
unnamed: D83.1, SW83.2
unnamed: D84.1, SW84.2
unnamed: D85.1, SW85.2
unnamed: D103.1, SW103.2
unnamed: D104.1, SW104.2
unnamed: D105.1, SW105.2
unnamed: D202.1, SW202.2
unnamed: D303.1, SW303.2
unnamed: D305.1, SW305.2
unnamed: D901.1, SW901.2
unnamed: J2.A, U2.4
unnamed: J2.B, R1.2, R2.2, U2.21
unnamed: J2.D, R1.1, U2.6
unnamed: SW_RST2.1, U2.22
unnamed: SW_RST2.2, U2.23
unnamed: U2.2, U2.3
SDA2: J2.C, R2.1, U2.5
row7: D31.2, D32.2, D33.2, D34.2, D35.2, D36.2, D37.2, D38.2, D39.2, D40.2, D41.2, U2.14
row8: D42.2, D43.2, D44.2, D45.2, D46.2, D47.2, D48.2, D49.2, D50.2, D51.2, D52.2, D53.2, U2.15
row9: D54.2, D55.2, D56.2, D57.2, D58.2, D59.2, D60.2, D61.2, D62.2, D63.2, U2.16
row10: D64.2, D65.2, D66.2, D67.2, D68.2, D69.2, D70.2, D901.2, U2.17
row11: D71.2, D72.2, D73.2, D74.2, D75.2, D76.2, D77.2, D78.2, D79.2, D80.2, D303.2, U2.18
row12: D81.2, D82.2, D83.2, D84.2, D85.2, D103.2, D104.2, D105.2, D202.2, D305.2, U2.19

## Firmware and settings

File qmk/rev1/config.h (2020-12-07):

/*
Copyright 2019 takashiski
Copyright 2020 kirin123kirin

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
You should have received a copy of the GNU General Public License
along with this program.  If not, see <http://www.gnu.org/licenses/>.
*/

#pragma once

#include "config_common.h"

/* USB Device descriptor parameter */
#define VENDOR_ID       0xFEED
#define PRODUCT_ID      0x0000
#define DEVICE_VER      0x0001
#define MANUFACTURER    kirin123kirin
#define PRODUCT         gammy
#define DESCRIPTION     A custom keyboard

/* key matrix size */
#define MATRIX_ROWS 12
#define MATRIX_COLS 12

/*
 * Keyboard Matrix Assignments
 *
 * Change this to how you wired your keyboard
 * COLS: AVR pins used for columns, left to right
 * ROWS: AVR pins used for rows, top to bottom
 * DIODE_DIRECTION: COL2ROW = COL = Anode (+), ROW = Cathode (-, marked on diode)
 *                  ROW2COL = ROW = Anode (+), COL = Cathode (-, marked on diode)
 *
*/
#define MATRIX_ROW_PINS { B7, B4, E6, D7, C6, D4 }
#define MATRIX_COL_PINS { B5, D5, C7, F1, F0, B6 }
#define MATRIX_ROW_PINS_RIGHT { B2, B3, B1, F7, F6, F5 }
#define MATRIX_COL_PINS_RIGHT { D4, C6, D7, E6, B4, B5, B7, D5, C7, F1, F0, B6 }
#define UNUSED_PINS

/* COL2ROW, ROW2COL*/
#define DIODE_DIRECTION COL2ROW

/*
 * Split Keyboard specific options, make sure you have 'SPLIT_KEYBOARD = yes' in your rules.mk, and define SOFT_SERIAL_PIN.
 */
#define SOFT_SERIAL_PIN D0 // or D1, D2, D3, E6
#define SPLIT_HAND_PIN D2 //fix pin. HIGH is left, LOW is right

#define USE_I2C

// #define BACKLIGHT_PIN B7
// #define BACKLIGHT_BREATHING
// #define BACKLIGHT_LEVELS 3

// #define RGB_DI_PIN E2
// #ifdef RGB_DI_PIN
//   #define RGBLED_NUM 16
//   #define RGBLIGHT_HUE_STEP 8
//   #define RGBLIGHT_SAT_STEP 8
//   #define RGBLIGHT_VAL_STEP 8
//   #define RGBLIGHT_LIMIT_VAL 255 /* The maximum brightness level */
//   #define RGBLIGHT_SLEEP  /* If defined, the RGB lighting will be switched off when the host goes to sleep */
// /*== all animations enable ==*/
//   #define RGBLIGHT_ANIMATIONS
// /*== or choose animations ==*/
//   #define RGBLIGHT_EFFECT_BREATHING
//   #define RGBLIGHT_EFFECT_RAINBOW_MOOD
//   #define RGBLIGHT_EFFECT_RAINBOW_SWIRL
//   #define RGBLIGHT_EFFECT_SNAKE
//   #define RGBLIGHT_EFFECT_KNIGHT
//   #define RGBLIGHT_EFFECT_CHRISTMAS
//   #define RGBLIGHT_EFFECT_STATIC_GRADIENT
//   #define RGBLIGHT_EFFECT_RGB_TEST
//   #define RGBLIGHT_EFFECT_ALTERNATING
// /*== customize breathing effect ==*/
//   /*==== (DEFAULT) use fixed table instead of exp() and sin() ====*/
//   #define RGBLIGHT_BREATHE_TABLE_SIZE 256      // 256(default) or 128 or 64
//   /*==== use exp() and sin() ====*/
//   #define RGBLIGHT_EFFECT_BREATHE_CENTER 1.85  // 1 to 2.7
//   #define RGBLIGHT_EFFECT_BREATHE_MAX    255   // 0 to 255
// #endif

/* Debounce reduces chatter (unintended double-presses) - set 0 if debouncing is not needed */
#define DEBOUNCE 5

/* define if matrix has ghost (lacks anti-ghosting diodes) */
//#define MATRIX_HAS_GHOST

/* number of backlight levels */

/* Mechanical locking support. Use KC_LCAP, KC_LNUM or KC_LSCR instead in keymap */
#define LOCKING_SUPPORT_ENABLE
/* Locking resynchronize hack */
#define LOCKING_RESYNC_ENABLE

/* If defined, GRAVE_ESC will always act as ESC when CTRL is held.
 * This is userful for the Windows task manager shortcut (ctrl+shift+esc).
 */
// #define GRAVE_ESC_CTRL_OVERRIDE

/*
 * Force NKRO
 *
 * Force NKRO (nKey Rollover) to be enabled by default, regardless of the saved
 * state in the bootmagic EEPROM settings. (Note that NKRO must be enabled in the
 * makefile for this to work.)
 *
 * If forced on, NKRO can be disabled via magic key (default = LShift+RShift+N)
 * until the next keyboard reset.
 *
 * NKRO may prevent your keystrokes from being detected in the BIOS, but it is
 * fully operational during normal computer usage.
 *
 * For a less heavy-handed approach, enable NKRO via magic key (LShift+RShift+N)
 * or via bootmagic (hold SPACE+N while plugging in the keyboard). Once set by
 * bootmagic, NKRO mode will always be enabled until it is toggled again during a
 * power-up.
 *
 */
//#define FORCE_NKRO

/*
 * Magic Key Options
 *
 * Magic keys are hotkey commands that allow control over firmware functions of
 * the keyboard. They are best used in combination with the HID Listen program,
 * found here: https://www.pjrc.com/teensy/hid_listen.html
 *
 * The options below allow the magic key functionality to be changed. This is
 * useful if your keyboard/keypad is missing keys and you want magic key support.
 *
 */

/* key combination for magic key command */
/* defined by default; to change, uncomment and set to the combination you want */
// #define IS_COMMAND() (get_mods() == (MOD_BIT(KC_LSHIFT) | MOD_BIT(KC_RSHIFT)))

/* control how magic key switches layers */
//#define MAGIC_KEY_SWITCH_LAYER_WITH_FKEYS  true
//#define MAGIC_KEY_SWITCH_LAYER_WITH_NKEYS  true
//#define MAGIC_KEY_SWITCH_LAYER_WITH_CUSTOM false
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

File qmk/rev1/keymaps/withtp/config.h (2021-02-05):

#pragma once


/*
 * Busywait Version :id=busywait-version
 * Note: This is not recommended, you may encounter jerky movement or unsent inputs. Please use interrupt or USART version if possible.
 */

#ifdef PS2_USE_BUSYWAIT
#   define PS2_CLOCK_PORT  PORTD
#   define PS2_CLOCK_PIN   PIND
#   define PS2_CLOCK_DDR   DDRD
#   define PS2_CLOCK_BIT   3
#   define PS2_DATA_PORT   PORTF
#   define PS2_DATA_PIN    PINF
#   define PS2_DATA_DDR    DDRF
#   define PS2_DATA_BIT    4
#endif



/*
 * Interrupt Version :id=interrupt-version
 * The following example uses B5 for clock and B6 for data. You can use any INT or PCINT pin for clock, and any pin for data.
 */

#ifdef PS2_USE_INT
#   define PS2_CLOCK_PORT  PORTB
#   define PS2_CLOCK_PIN   PINB
#   define PS2_CLOCK_DDR   DDRB
#   define PS2_CLOCK_BIT   5
#   define PS2_DATA_PORT   PORTB
#   define PS2_DATA_PIN    PINB
#   define PS2_DATA_DDR    DDRB
#   define PS2_DATA_BIT    6

#   define PS2_INT_INIT()  do {    \
       PCICR |= (1<<PCIE0);        \
    } while (0)
#   define PS2_INT_ON()  do {      \
       PCMSK0 |= (1<<PCINT5);      \
    } while (0)
#   define PS2_INT_OFF() do {      \
       PCMSK0 &= ~(1<<PCINT5);     \
    } while (0)
#   define PS2_INT_VECT   PCINT0_vect
#endif

/*
 * USART Version :id=usart-version
 * To use USART on the ATMega32u4, you have to use PD5 for clock and PD2 for data. If one of those are unavailable, you need to use interrupt version.
 *   synchronous, odd parity, 1-bit stop, 8-bit data, sample at falling edge
 *   set DDR of CLOCK as input to be slave
 */

#ifdef PS2_USE_USART
#   define PS2_CLOCK_PORT  PORTD
#   define PS2_CLOCK_PIN   PIND
#   define PS2_CLOCK_DDR   DDRD
#   define PS2_CLOCK_BIT   5
#   define PS2_DATA_PORT   PORTD
#   define PS2_DATA_PIN    PIND
#   define PS2_DATA_DDR    DDRD
#   define PS2_DATA_BIT    2

#   define PS2_USART_INIT() do {   \
       PS2_CLOCK_DDR &= ~(1<<PS2_CLOCK_BIT);   \
       PS2_DATA_DDR &= ~(1<<PS2_DATA_BIT);     \
       UCSR1C = ((1 << UMSEL10) |  \
                 (3 << UPM10)   |  \
                 (0 << USBS1)   |  \
                 (3 << UCSZ10)  |  \
                 (0 << UCPOL1));   \
       UCSR1A = 0;                 \
       UBRR1H = 0;                 \
       UBRR1L = 0;                 \
    } while (0)
#   define PS2_USART_RX_INT_ON() do {  \
       UCSR1B = ((1 << RXCIE1) |       \
                 (1 << RXEN1));        \
    } while (0)
#   define PS2_USART_RX_POLL_ON() do { \
       UCSR1B = (1 << RXEN1);          \
    } while (0)
#   define PS2_USART_OFF() do {    \
       UCSR1C = 0;                 \
       UCSR1B &= ~((1 << RXEN1) |  \
                   (1 << TXEN1));  \
    } while (0)
#   define PS2_USART_RX_READY      (UCSR1A & (1<<RXC1))
#   define PS2_USART_RX_DATA       UDR1
#   define PS2_USART_ERROR         (UCSR1A & ((1<<FE1) | (1<<DOR1) | (1<<UPE1)))
#   define PS2_USART_RX_VECT       USART1_RX_vect
#endif

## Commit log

2020-12-08 手順メモ
2020-12-09 case build
    [basic.dxf]
2020-12-12 case data make
    [basic.dxf, basic_L_plate.stl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]
2020-12-13 bugfix. and PCB Data Elecrow ordered
    [basic.dxf, keyboard-layouter-playground.kicad_pcb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]
2020-12-15 case closed edited.
    [case_L_top.stl]
2020-12-25 pcb bugfix trrs hole add
    [keyboard-layouter-playground.kicad_pcb]
2020-12-27 left promicro both OK.
    [keyboard-layouter-playground.kicad_pcb, keyboard-layouter-playground.sch]
2020-12-29 case update.
    [case_L_top.stl, case_R_top.stl, plate_L.dxf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]
2021-01-11 stable. bugfixed
    [case_L_bottom.stl, case_L_top.stl, case_R_bottom.stl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]
2021-02-05 bugfix datasheet add
    [DATASHEET.xlsx]
2021-12-20 keyboard settings and added arrows_R
    [full.kicad_pcb, full.sch, trackpoint.kicad_pcb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]

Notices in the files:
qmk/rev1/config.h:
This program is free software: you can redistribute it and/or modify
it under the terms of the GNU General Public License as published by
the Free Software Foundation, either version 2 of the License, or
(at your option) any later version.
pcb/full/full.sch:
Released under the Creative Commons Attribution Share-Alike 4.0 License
